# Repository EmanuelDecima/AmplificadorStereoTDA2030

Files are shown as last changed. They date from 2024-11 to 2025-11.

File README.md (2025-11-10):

# Amplificador Estéreo TDA2030  
   

## Descripción  
Este proyecto es un **amplificador estéreo basado en el integrado TDA2030**, diseñado para ofrecer una solución compacta y de buen desempeño para aplicaciones de audio Hi-Fi, educación y prototipado. El diseño incluye PCB, esquemático, lista de materiales y archivos listos para fabricación.

## 🔧 Características principales  
- Dos canales de audio (izquierda y derecha) utilizando TDA2030 en configuración típica.  
- Diseño de PCB simple faz, con huella optimizada para montaje a través de orificio (THT).
- Fuente de alimentación simple (recomendado 12VDC).
- Listado de materiales (BOM) incluido en formatos PDF y XLS.  
- Archivos de fabricación (Gerbers, ficheros KiCad) incluidos.  
- Ideal para amplificación de señal de línea, sistemas de escritorio, audio doméstico o proyecto educativo.

## 🖼️ Esquema y PCB  
*(Insertar imágenes aquí para visualización rápida)*  
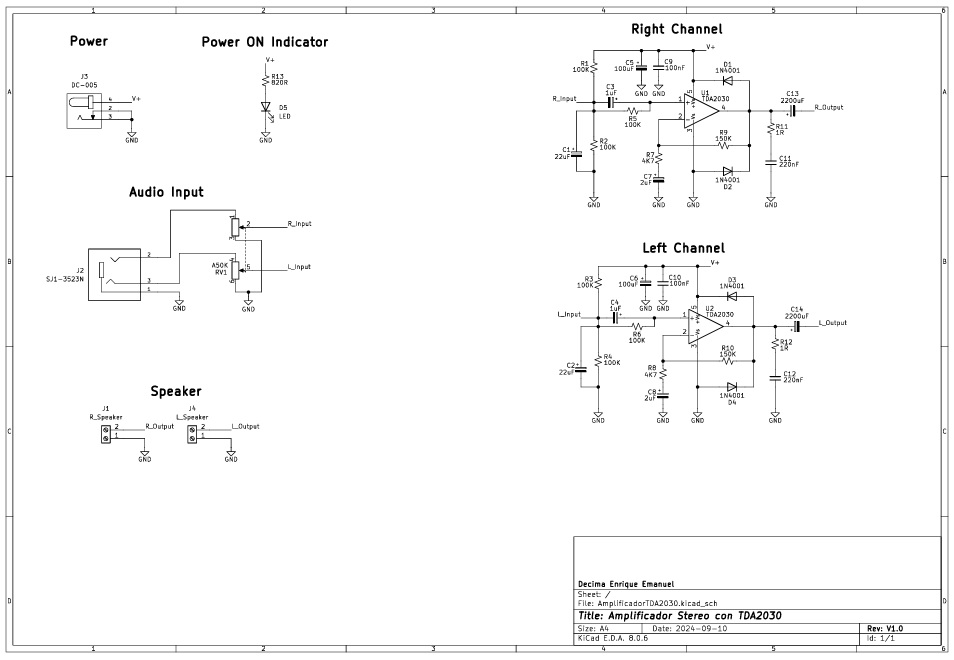
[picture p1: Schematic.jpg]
Esquemático
  
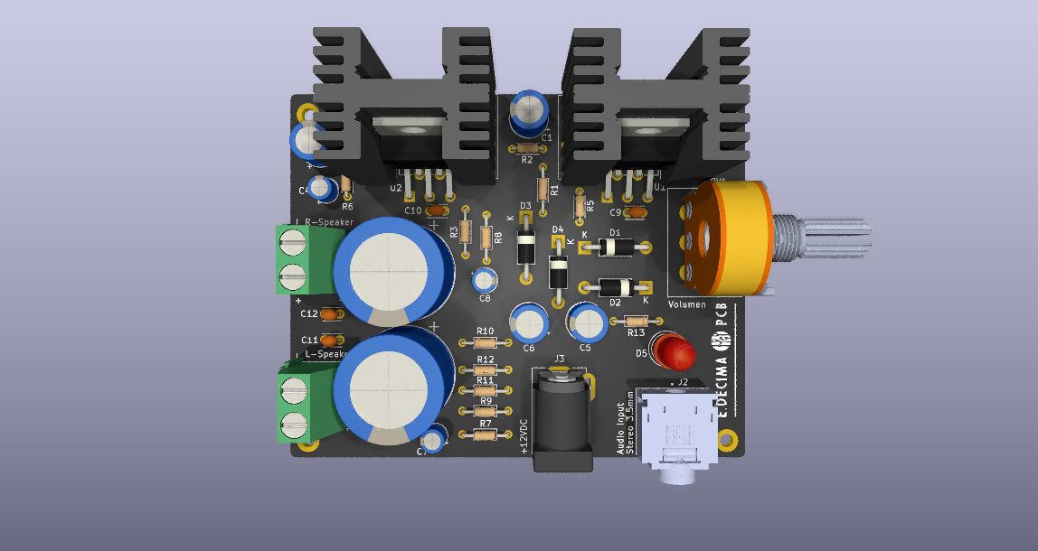
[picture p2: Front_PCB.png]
Vista PCB – frontal
  
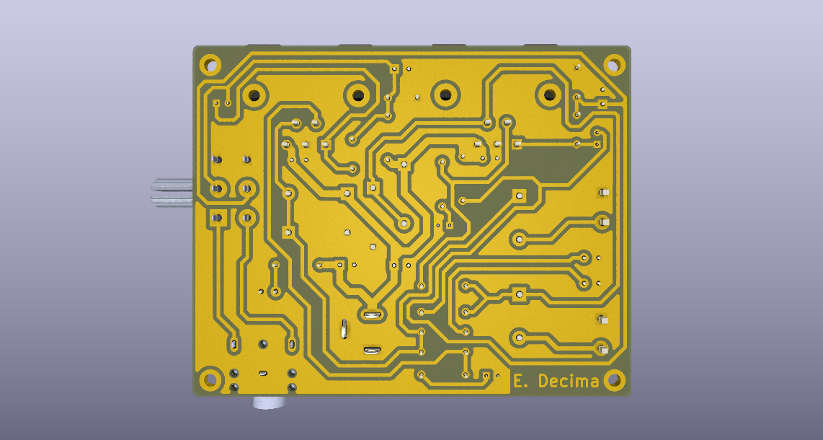
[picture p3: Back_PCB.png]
Vista PCB – trasera


## ⚙️ Documentación técnica  
### Arquitectura general  
El amplificador emplea dos unidades TDA2030, una por canal, en configuración con decouplado de alimentación, filtro de entrada y componentes de realimentación para ganancia moderada (~20–30x).  
Se dispone de conectores de entrada de audio de línea, potenciometro/selector de ganancia, y salidas de altavoz de 4 Ω-8 Ω.

### Consideraciones de diseño  
- Se recomienda usar disipadores térmicos en los TDA2030 si la potencia exigida es alta.
- La entrada de audio debe ser preamplificada anteriormente hasta el voltaje de linea 1Vrms.

## 🧰 Requisitos y compatibilidad  
### Requisitos  
- Fuente de alimentación de 12V-DC.
- Altavoces de impedancia 4Ω o 8Ω.  
- Señal de entrada de nivel de línea 1Vrms.  
- Habilidades básicas de soldadura para montaje THT.

### Compatibilidad  
Este diseño está pensado para montaje en ambiente “hobby/prototipo” y también escalable para proyectos de audio doméstico o educativo.

## 💻 Ejemplo de uso  
1. Montar la PCB según el archivo de montaje y la lista de materiales.  
2. Conectar la alimentación y verificar tensiones (sin señal).  
3. Conectar entrada y altavoces.  
4. Aplicar señal de audio de línea, ajustar volumen, y comprobar ganancia, distorsión y estabilidad.  
5. Ajustar según necesidades (por ejemplo añadir filtro de paso bajo, control de volumen, etc).

## 👤 Autor  
Diseñado por Emanuel Décima  
📅 Fecha de última actualización: Noviembre 2025  
📧 Contacto: emanueldecima3@gmail.com

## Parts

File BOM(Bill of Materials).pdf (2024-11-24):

Componente | Cant. | Precio Unitario | Subtotal
TDA2030 | 2 | $ | $ 5.263,40 2.631,70
Conector DC-005 | 1 | $ | $ 862,20 862,20
Conector Audio Stereo 3,5mm | 1 | $ | $ 2.914,57 2.914,57
Bornera de 2 Entradas | 2 | $ | $ 2.603,50 1.301,75
Led 5mm | 1 | $ | $ 1.490,00 1.490,00
Potenciometro Doble A50K | 1 | $ | $ 4.023,00 4.023,00
Resistencia 150K a 1/4W | 2 | $ | $ 596,00 298,00
Resistencia 100K a 1/4W | 6 | $ | $ 1.788,00 298,00
Resistencia 4K7 a 1/4W | 2 | $ | $ 596,00 298,00
Resistencia 820R a 1/4W | 1 | $ | $ 298,00 298,00
Resistencia 1R a 1/4W | 2 | $ | $ 596,00 298,00
Diodo 1N4001 | 4 | $ | $ 664,00 166,00
Capacitor Electrolitico 2200uF/35V | 2 | $ | $ 5.948,30 2.974,15
Capacitor Electrolitico 100uF/35V | 2 | $ | $ 967,78 483,89
Capacitor Electrolitico 22uF/35V | 2 | $ | $ 400,00 200,00
Capacitor Electrolitico 2,2uF/35V | 2 | $ | $ 189,12 94,56
Capacitor Electrolitico 1uF/35V | 2 | $ | $ 258,00 129,00
Capacitor Ceramico 100nF | 2 | $ | $ 200,00 100,00
Capacitor Ceramico 220nF | 2 | $ | $ 200,00 100,00
Total | $ | 29.857,87

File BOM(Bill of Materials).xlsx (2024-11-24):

Componente | Cant. | Precio Unitario | Subtotal
TDA2030 | 2 | $2631.70 | $5263.40
Conector DC-005 | 1 | $862.20 | $862.20
Conector Audio Stereo 3,5mm | 1 | $2914.57 | $2914.57
Bornera de 2 Entradas | 2 | $1301.75 | $2603.50
Led 5mm | 1 | $1490.00 | $1490.00
Potenciometro Doble A50K | 1 | $4023.00 | $4023.00
Resistencia 150K a 1/4W | 2 | $298.00 | $596.00
Resistencia 100K a 1/4W | 6 | $298.00 | $1788.00
Resistencia 4K7 a 1/4W | 2 | $298.00 | $596.00
Resistencia 820R a 1/4W | 1 | $298.00 | $298.00
Resistencia 1R a 1/4W | 2 | $298.00 | $596.00
Diodo 1N4001 | 4 | $166.00 | $664.00
Capacitor Electrolitico 2200uF/35V | 2 | $2974.15 | $5948.30
Capacitor Electrolitico 100uF/35V | 2 | $483.89 | $967.78
Capacitor Electrolitico 22uF/35V | 2 | $200.00 | $400.00
Capacitor Electrolitico 2,2uF/35V | 2 | $94.56 | $189.12
Capacitor Electrolitico 1uF/35V | 2 | $129.00 | $258.00
Capacitor Ceramico 100nF | 2 | $100.00 | $200.00
Capacitor Ceramico 220nF | 2 | $100.00 | $200.00
Total |  | $29857.87

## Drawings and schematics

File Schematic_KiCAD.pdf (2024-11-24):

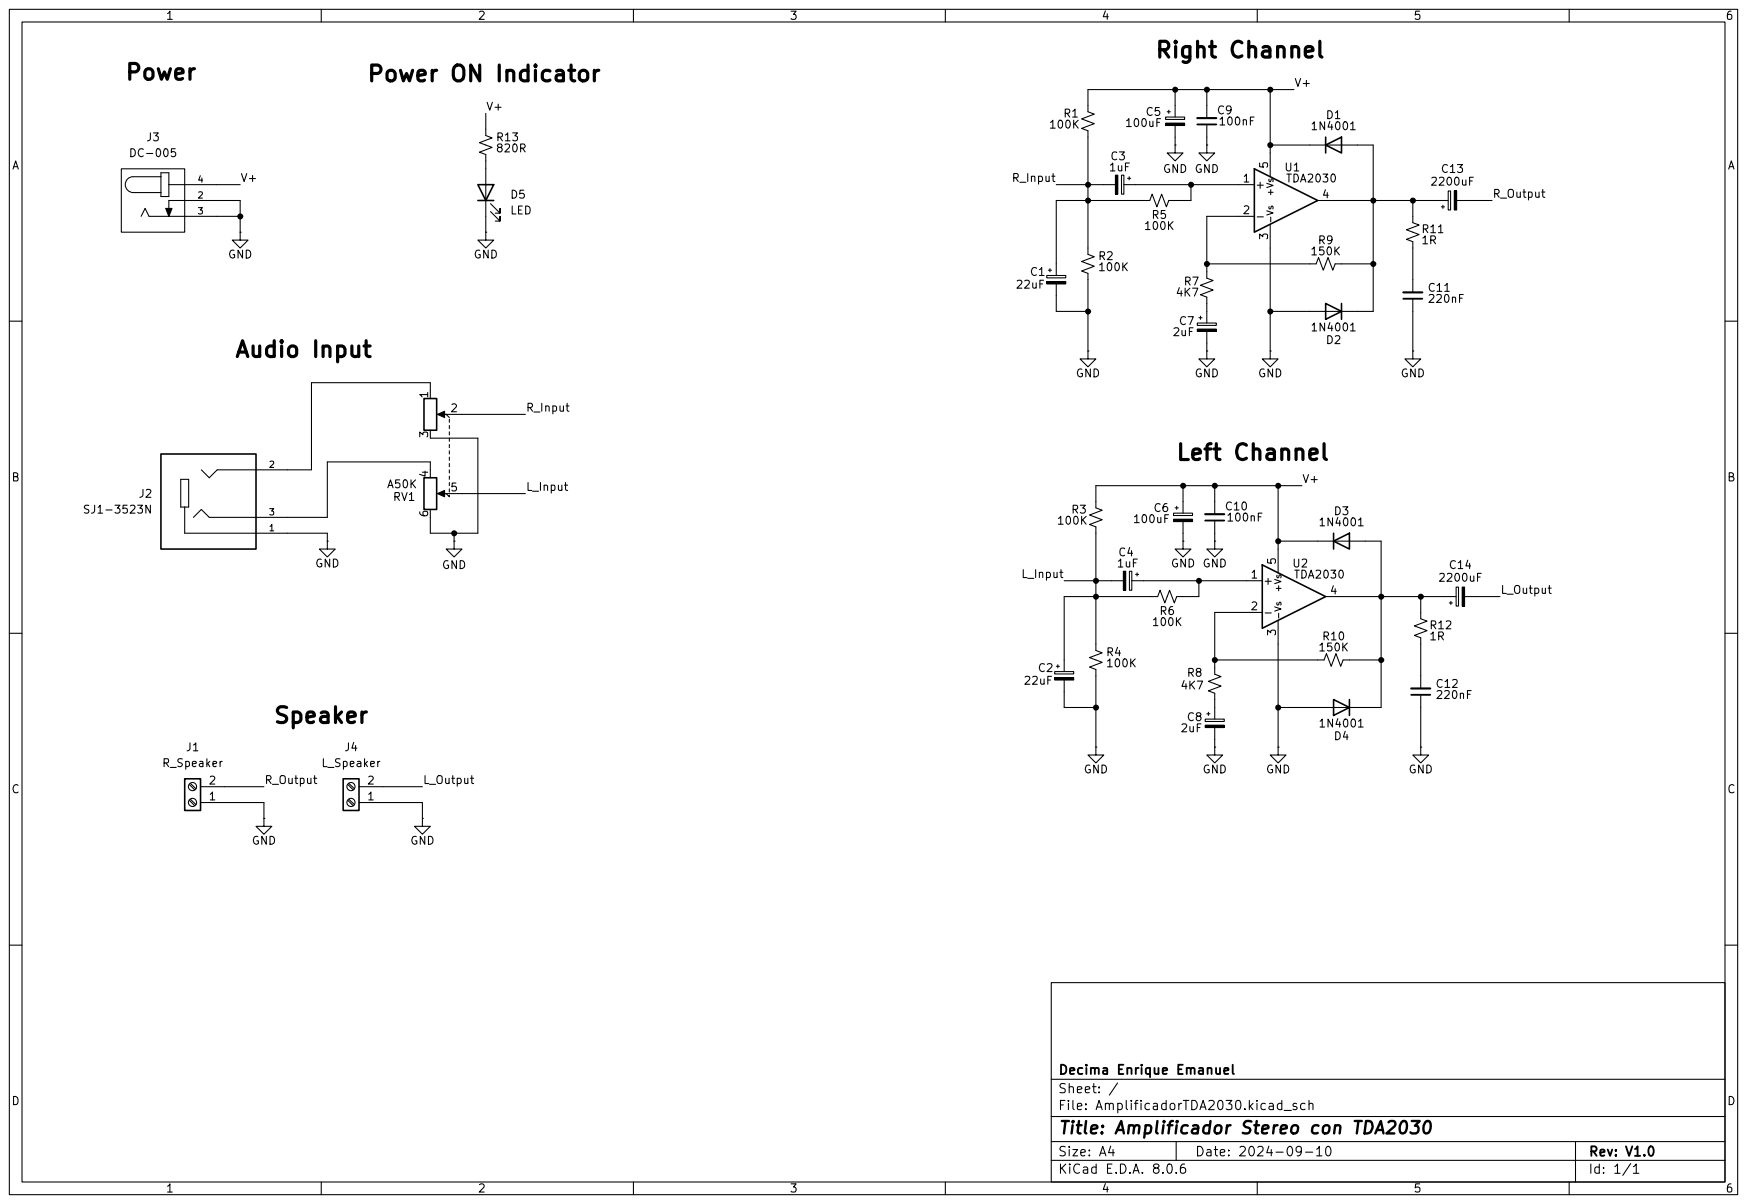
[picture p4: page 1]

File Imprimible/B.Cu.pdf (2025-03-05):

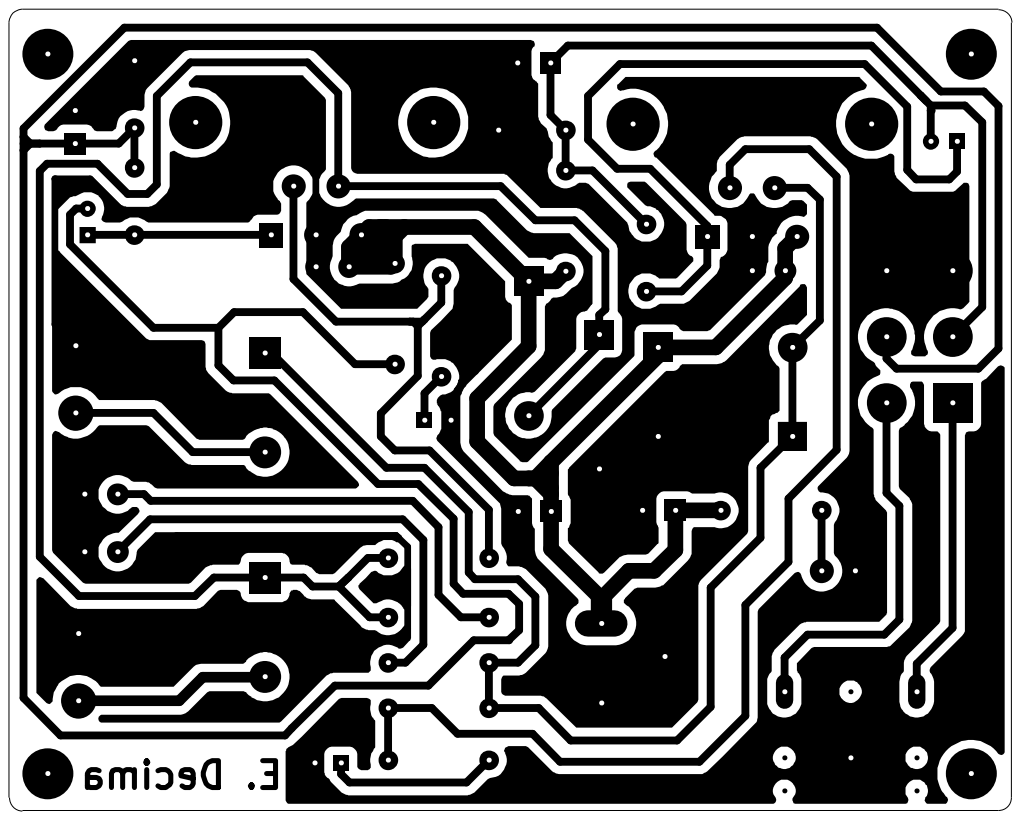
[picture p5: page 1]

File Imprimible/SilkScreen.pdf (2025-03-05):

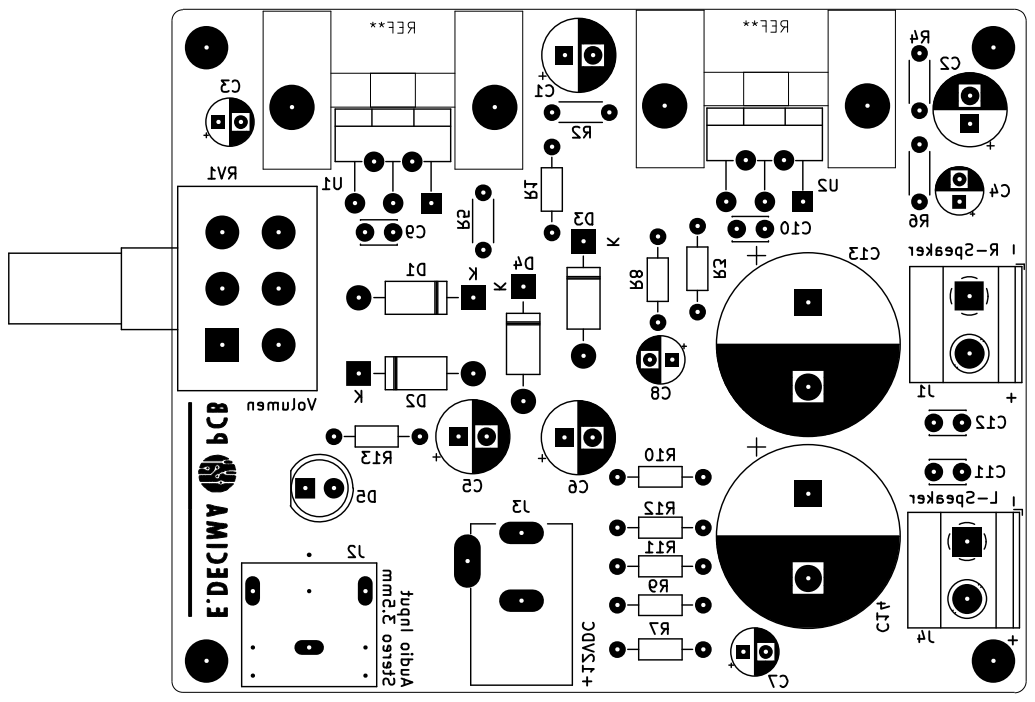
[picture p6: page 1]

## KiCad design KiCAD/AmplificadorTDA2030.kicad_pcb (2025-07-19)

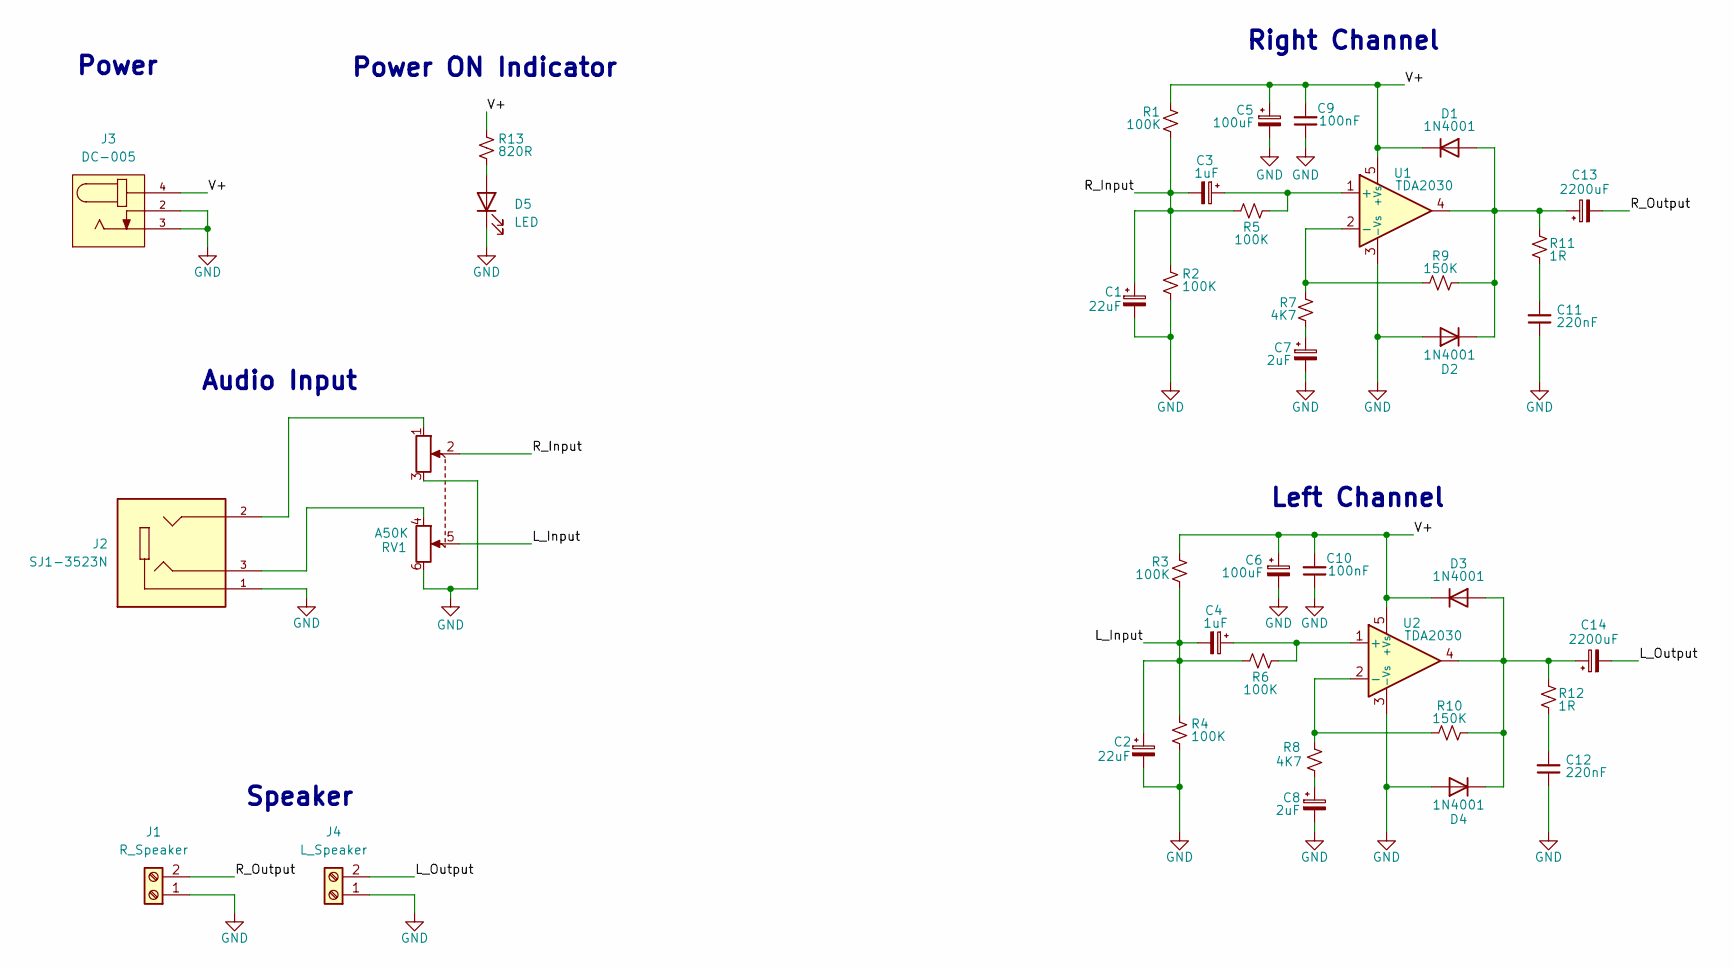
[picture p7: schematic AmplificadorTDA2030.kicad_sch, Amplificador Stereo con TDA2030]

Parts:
C1, C2: 22uF; CP_Radial_D6.3mm_P2.50mm
C3, C4: 1uF; CP_Radial_D4.0mm_P2.00mm
C5, C6: 100uF; CP_Radial_D6.3mm_P2.50mm
C7, C8: 2uF; CP_Radial_D4.0mm_P2.00mm
C9, C10: 100nF; C_Disc_D3.0mm_W2.0mm_P2.50mm
C11, C12: 220nF; C_Disc_D3.0mm_W2.0mm_P2.50mm
C13, C14: 2200uF; CP_Radial_D16.0mm_P7.50mm
D1, D2, D3, D4: 1N4001; D_DO-41_SOD81_P10.16mm_Horizontal
D5: LED; LED_D5.0mm
J1: R_Speaker; TerminalBlock_Phoenix_MKDS-1,5-2-5.08_1x02_P5.08mm_Horizont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
J2: SJ1-3523N; CUI_SJ1-3523N; PARTREV 1.05
J3: DC-005; NINIGI_DC-005
J4: L_Speaker; TerminalBlock_Phoenix_MKDS-1,5-2-5.08_1x02_P5.08mm_Horizont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
R1, R3: 100K; R_Axial_DIN0204_L3.6mm_D1.6mm_P7.62mm_Horizontal
R2, R4, R5, R6: 100K; R_Axial_DIN0204_L3.6mm_D1.6mm_P5.08mm_Horizontal
R7, R8: 4K7; R_Axial_DIN0204_L3.6mm_D1.6mm_P7.62mm_Horizontal
R9, R10: 150K; R_Axial_DIN0204_L3.6mm_D1.6mm_P7.62mm_Horizontal
R11, R12: 1R; R_Axial_DIN0204_L3.6mm_D1.6mm_P7.62mm_Horizontal
R13: 820R; R_Axial_DIN0204_L3.6mm_D1.6mm_P7.62mm_Horizontal
RV1: A50K; Potentiometer_Alps_RK163_Dual_Horizontal
U1, U2: TDA2030; TO-220-5_P3.4x3.7mm_StaggerOdd_Lead3.8mm_Vertical

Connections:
/L_Input: C2.1, C4.2, R3.1, R4.2, R6.1, RV1.5
/L_Output: C14.2, J4.2
/R_Input: C1.1, C3.2, R1.1, R2.2, R5.1, RV1.2
/R_Output: C13.2, J1.2
/V+: C5.1, C6.1, C9.2, C10.2, D1.1 (K), D3.1 (K), J3.4, R1.2, R3.2, R13.2, U1.5 (+Vs), U2.5 (+Vs)
GND: C1.2, C2.2, C5.2, C6.2, C7.2, C8.2, C9.1, C10.1, C11.1, C12.1, D2.2 (A), D4.2 (A), D5.1 (K), J1.1, J2.1, J3.2, J3.3, J4.1, R2.1, R4.1, RV1.3, RV1.6, U1.3 (-Vs), U2.3 (-Vs)
unnamed: C7.1, R7.1
unnamed: C8.1, R8.1
unnamed: C11.2, R11.1
unnamed: C12.2, R12.1
unnamed: C13.1, D1.2 (A), D2.1 (K), R9.1, R11.2, U1.4
unnamed: C14.1, D3.2 (A), D4.1 (K), R10.1, R12.2, U2.4
unnamed: D5.2 (A), R13.1
unnamed: J2.2, RV1.1
unnamed: J2.3, RV1.4
unnamed: C3.1, R5.2, U1.1 (+)
unnamed: R7.2, R9.2, U1.2 (-)
unnamed: C4.1, R6.2, U2.1 (+)
unnamed: R8.2, R10.2, U2.2 (-)

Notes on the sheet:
Right Channel
Power ON Indicator
Power
Speaker
Left Channel
Audio Input

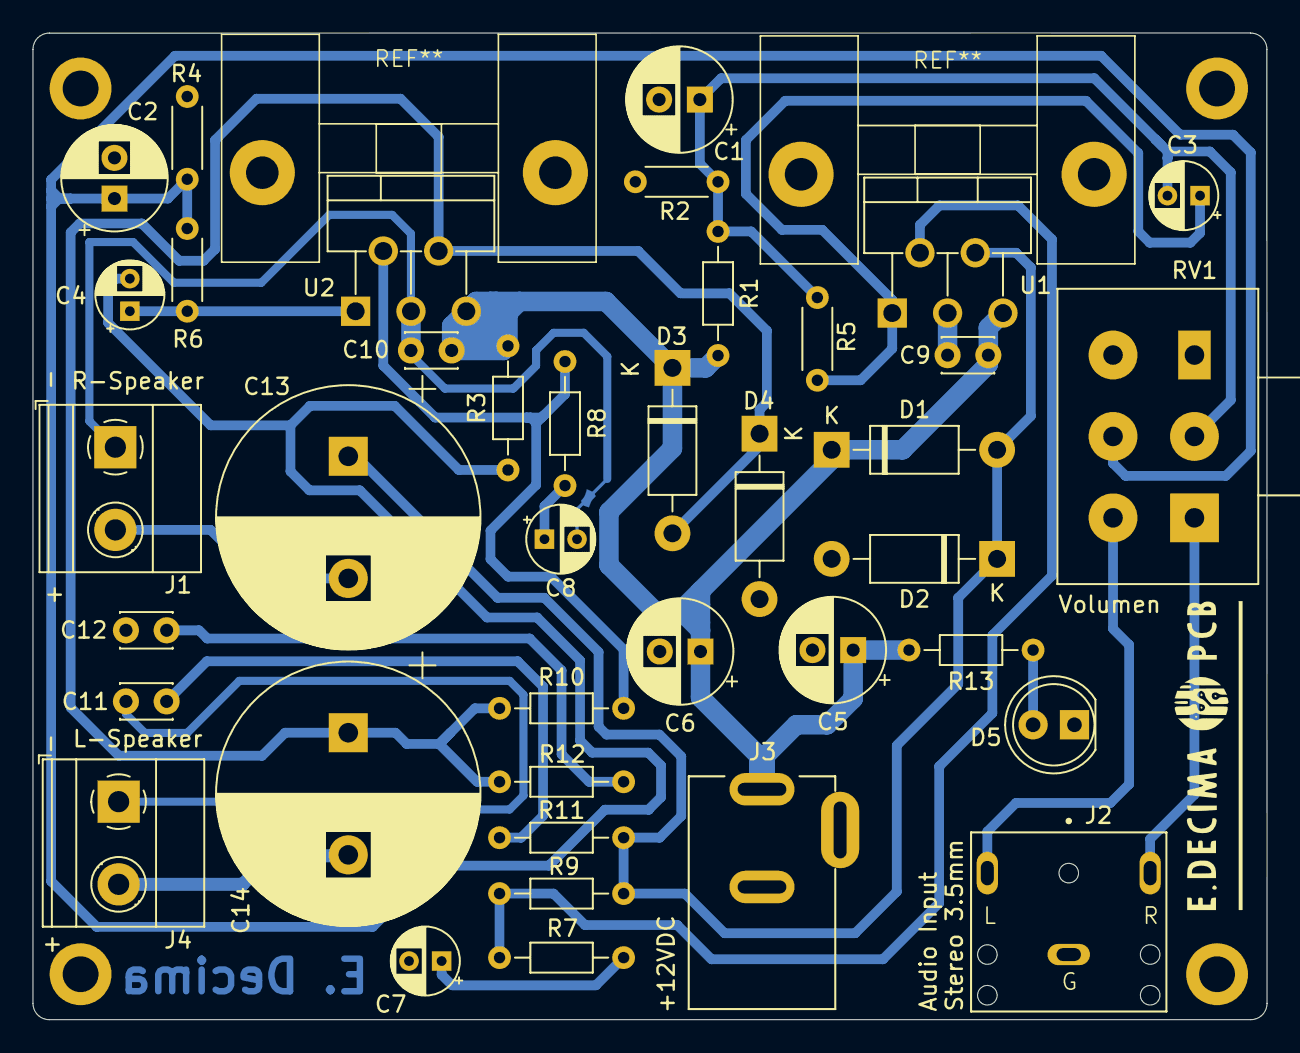
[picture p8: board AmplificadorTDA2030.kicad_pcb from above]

Board: 2 copper layers, 75.8 x 60.6 mm, 39 parts (0 on the bottom side), 19 nets.

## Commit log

2024-09-25 Se agrega Esquematico y BOM
    [AmplificadorTDA2030.kicad_pcb, BOM.xlsx]
2024-09-25 Librerias de Simbolos,Footprints y Modelos 3D Agregados
    [AmplificadorTDA2030.kicad_pcb, AmplificadorTDA2030.kicad_sch]
2024-09-26 Footprints Asignados
    [AmplificadorTDA2030.kicad_pcb, AmplificadorTDA2030.kicad_sch, BOM.xlsx]
2024-09-27 Ruteo de PCB correcto
    [AmplificadorTDA2030.kicad_pcb, AmplificadorTDA2030.kicad_sch]
2024-10-01 Se agrega LED y Disipadores
    [AmplificadorTDA2030.kicad_pcb, AmplificadorTDA2030.kicad_sch]
2024-10-01 Documentacion Actualizada
    [AmplificadorTDA2030.kicad_pcb]
2024-11-20 Acutalizacion de Doc
    [AmplificadorTDA2030.kicad_pcb]
2024-11-24 Reorganizacion de Carpetas y Actualizacion de Documentacion
    [AmplificadorTDA2030.kicad_pcb, AmplificadorTDA2030.kicad_sch, BOM(Bill of Materials).xlsx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]
2024-11-24 Agrego diseño mecanico en AutoCAD
    [AmplificadorTDA2030.kicad_pcb]
2025-03-05 Archivos Imprimibles
    [AmplificadorTDA2030.kicad_pcb, AmplificadorTDA2030.kicad_sch, MechanicalDesignAutoCAD.dwg]
2025-07-19 Imagenes de PCB
    [AmplificadorTDA2030.kicad_pcb]
2025-11-10 Fix image path for schematic in README
2025-11-10 Update schematic image from PDF to JPG format

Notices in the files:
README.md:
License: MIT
